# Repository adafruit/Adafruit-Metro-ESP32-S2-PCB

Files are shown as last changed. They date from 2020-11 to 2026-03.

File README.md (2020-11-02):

## Adafruit Metro ESP32-S2 PCB

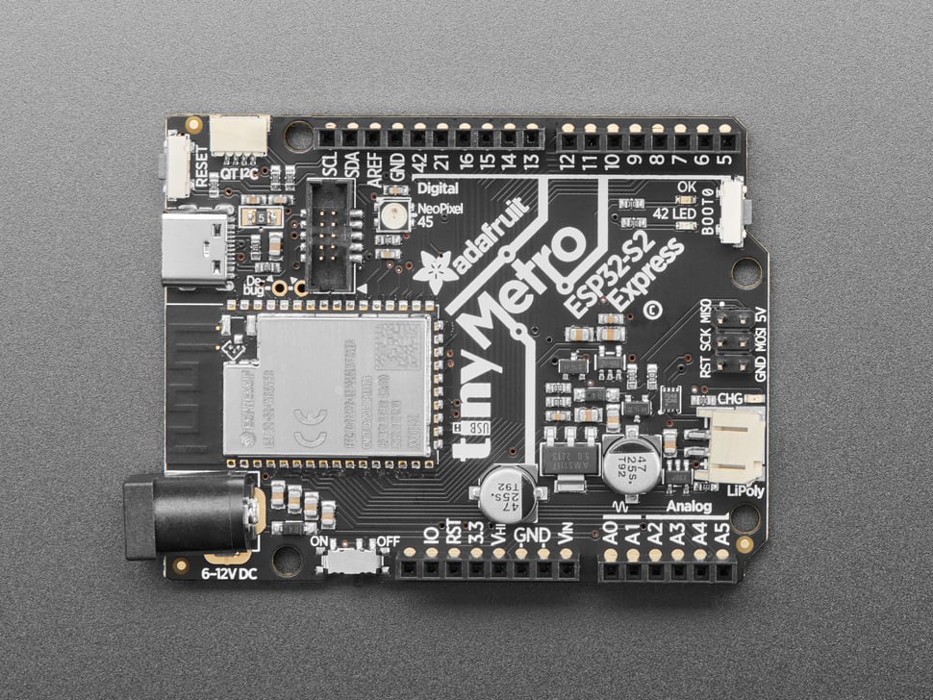
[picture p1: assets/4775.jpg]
<a href="http://www.adafruit.com/products/4775"><br/>
Click here to purchase one from the Adafruit shop</a>

PCB files for the Adafruit Metro ESP32-S2.

Format is EagleCAD schematic and board layout
* https://www.adafruit.com/product/4775

### Description

What's Metro shaped and has an ESP32-S2 WiFi module? What has a STEMMA QT connector for I2C devices, and a Lipoly charger circuit? What's finishing up testing and nearly ready for fabrication? That's right - its the new Adafruit Metro ESP32-S2! With native USB and a load of PSRAM this board is perfect for use with CircuitPython or Arduino, to add low-cost WiFi while keeping shield-compatibility

Features:

* ESP32-S2 240MHz Tensilica processor - the next generation of ESP32, now with native USB so it can act like a keyboard/mouse, MIDI device, disk drive, etc!
* WROVER module has FCC/CE certification and comes with 4 MByte of Flash and 8 MByte of PSRAM - you can have huge data buffers
* Lotsa power options - 6-12VDC barrel jack or USB type C or Lipoly battery
* Built-in battery charging when powered over DC or USB
* UNO-shape so shields can plug in
* Reset and DFU (BOOT0) buttons to get into the ROM bootloader (which is a USB serial port so you don't need a separate cable!)
* Serial debug pins (optional, for checking the hardware serial debug console)
* JTAG pads for advanced debugging access.
* On/Off switch
* STEMMA QT connector for I2C devices
* On/Charge/User LEDs + status NeoPixel
* Works with Arduino or CircuitPython
* 53.2mm x 72mm / 2" x 2.8"
* Height (w/ barrel jack): 14.8mm / 0.6"
* Weight: 22.5g

### License

Adafruit invests time and resources providing this open source design, please support Adafruit and open-source hardware by purchasing products from [Adafruit](https://www.adafruit.com)!

Designed by Limor Fried/Ladyada for Adafruit Industries.

Creative Commons Attribution/Share-Alike, all text above must be included in any redistribution.
See license.txt for additional details.

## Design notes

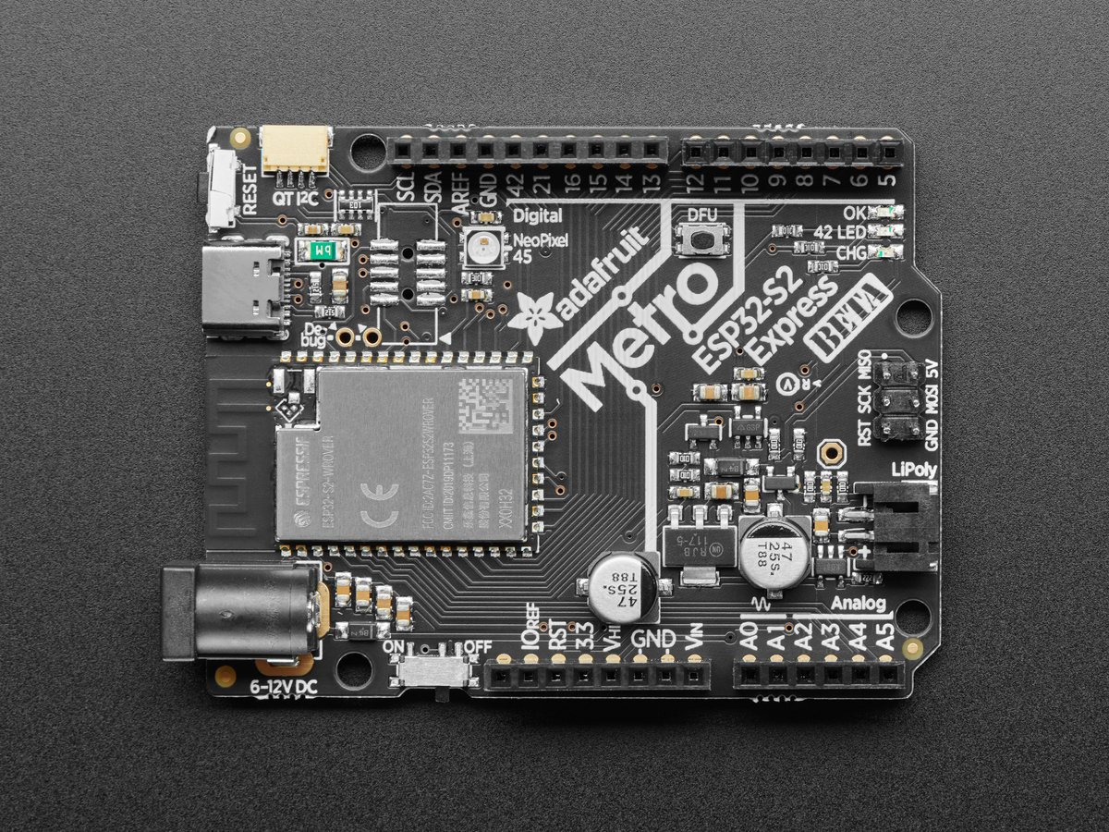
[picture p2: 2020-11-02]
assets/4775_revA.jpg

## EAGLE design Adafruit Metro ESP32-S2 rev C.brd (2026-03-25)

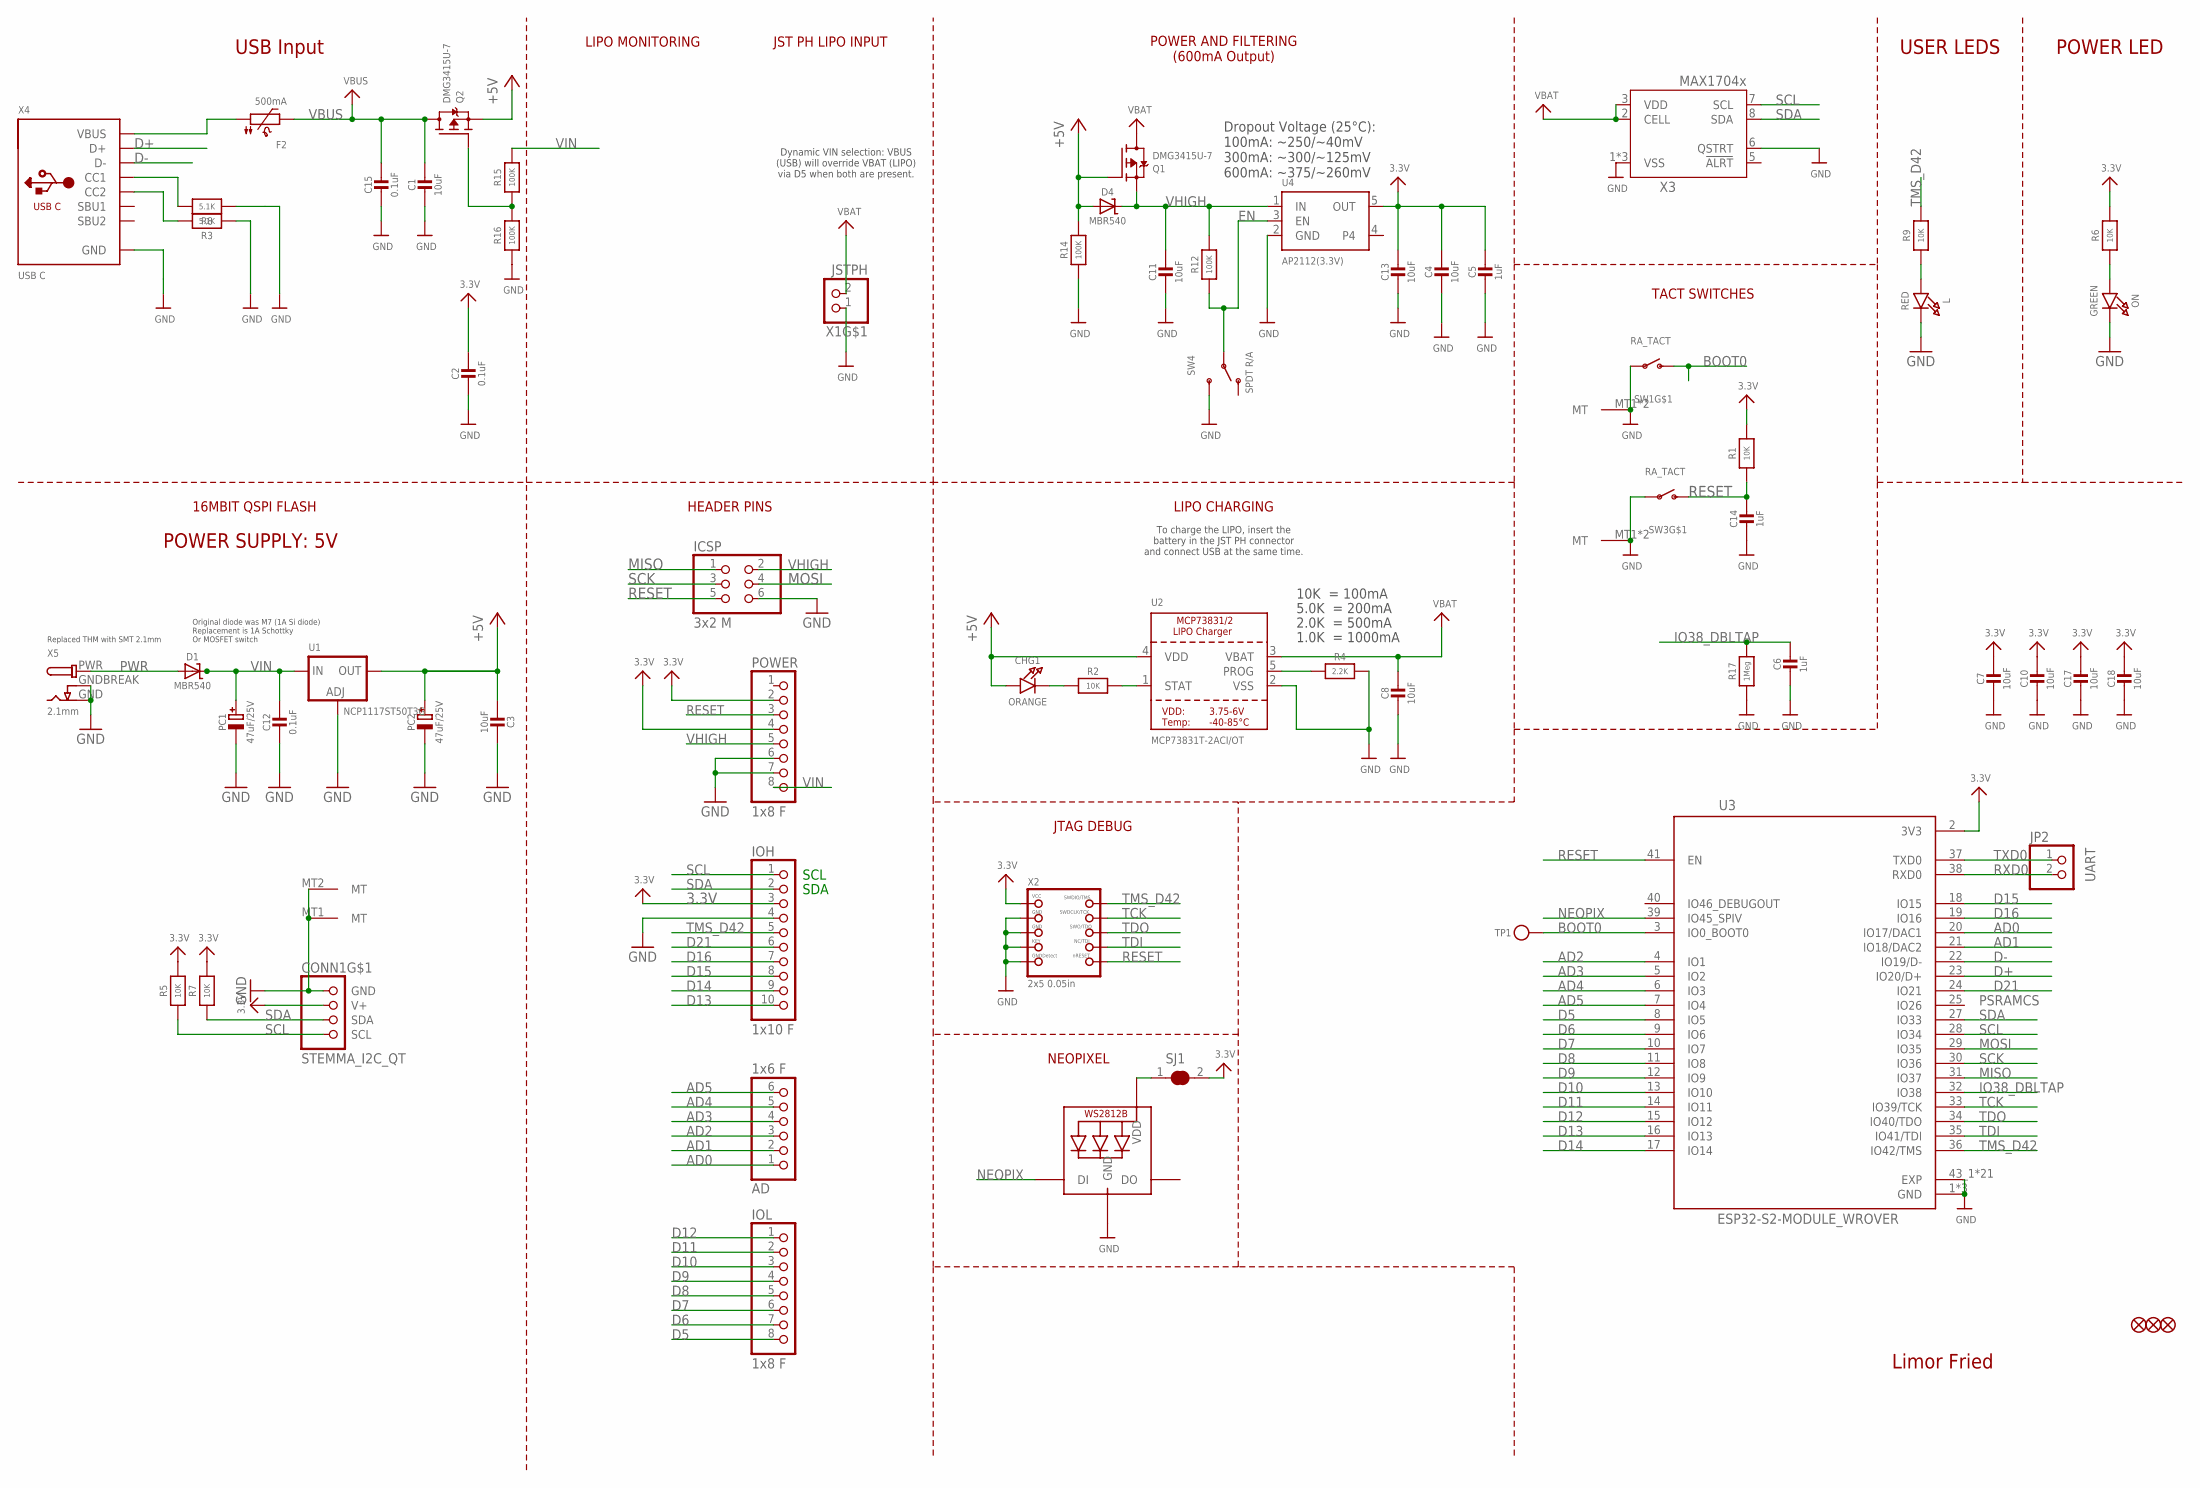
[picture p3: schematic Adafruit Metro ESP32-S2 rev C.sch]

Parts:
AD: 1x6 F; 1X06_OVALWAVE
C1, C3, C4, C7, C8, C10, C11, C13, C17, C18: 10uF; 0805-NO
C2, C12, C15: 0.1uF; 0603-NO
C5, C6, C14: 1uF; 0603-NO
CHG1: ORANGE; CHIPLED_0603_NOOUTLINE
CONN1: STEMMA_I2C_QT; JST_SH4
D1, D4: MBR540; SOD-123
F2: 500mA; 1206
FD1, FD2, FD3: FIDUCIAL_1MM
ICSP: 3x2 M; 2X03_ROUND_70MIL
IOH: 1x10 F; 1X10_OVALWAVE
IOL: 1x8 F; 1X08_OVALWAVE
JP2: UART; 1X02_ROUND
L: RED; CHIPLED_0603_NOOUTLINE
LED1: WS2812B_3535FULL; LED3535_FULLPADS
ON: GREEN; CHIPLED_0603_NOOUTLINE
PC1, PC2: 47uF/25V; PANASONIC_D
POWER: 1x8 F; 1X08_OVALWAVE
Q1, Q2: DMG3415U-7; SOT23-R
R1, R2, R5, R6, R7, R9: 10K; 0603-NO
R3, R8: 5.1K; 0603-NO
R4: 2.2K; 0603-NO
R12, R14, R15, R16: 100K; 0603-NO
R17: 1Meg; 0603-NO
SJ1: SOLDERJUMPER_CLOSED; SOLDERJUMPER_CLOSEDWIRE
SW1, SW3: RA_TACT; SPST_TACTILE_RA
SW4: SPDT R/A; SPDT_SMT_SSSS811101
TP1: TESTPOINTROUND1.5MMNO; TESTPOINT_ROUND_1.5MM_NO
U1: NCP1117ST50T3G; SOT223-R
U2: MCP73831T-2ACI/OT; SOT23-5
U3: ESP32-S2-MODULE_WROVER; MODULE_ESP32-S2-WROVER
U4: AP2112(3.3V); SOT23-5; JLC_ROTATION 0
X1: JSTPH; JSTPH2_BATT
X2: 2x5 0.05in; 2X05_1.27MM_BOX_POSTS
X3: MAX17048/T; TDFN8_2X2MM
X4: USB C; USB_C_CUSB31-CFM2AX-01-X
X5: 2.1mm; DCJACK_2MM_PTH

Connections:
3.3V: C2.1, C4.1, C5.1, C7.1, C10.1, C13.1, C17.1, C18.1, CONN1.2 (V+), IOH.3, POWER.2, POWER.4, R1.2, R5.2, R6.2, R7.2, SJ1.2, U3.2 (3V3), U4.5 (OUT), X2.1 (VCC)
+5V: C3.2, CHG1.A, D4.A, PC2.+, Q1.1 (G), Q2.2 (S), R14.2, U1.2 (OUT), U1.4 (OUT), U2.4 (VDD)
AD0: AD.1, U3.20 (IO17/DAC1)
AD1: AD.2, U3.21 (IO18/DAC2)
AD2: AD.3, U3.4 (IO1)
AD3: AD.4, U3.5 (IO2)
AD4: AD.5, U3.6 (IO3)
AD5: AD.6, U3.7 (IO4)
BOOT0: SW1.2 (S), TP1.P$1, U3.3 (IO0_BOOT0)
D5: IOL.8, U3.8 (IO5)
D6: IOL.7, U3.9 (IO6)
D7: IOL.6, U3.10 (IO7)
D8: IOL.5, U3.11 (IO8)
D9: IOL.4, U3.12 (IO9)
D10: IOL.3, U3.13 (IO10)
D11: IOL.2, U3.14 (IO11)
D12: IOL.1, U3.15 (IO12)
D13: IOH.10, U3.16 (IO13)
D14: IOH.9, U3.17 (IO14)
D15: IOH.8, U3.18 (IO15)
D16: IOH.7, U3.19 (IO16)
D21: IOH.6, U3.24 (IO21)
D+: U3.23 (IO20/D+), X4.A6 (D+), X4.B6 (D+)
D-: U3.22 (IO19/D-), X4.A7 (D-), X4.B7 (D-)
EN: R12.1, SW4.B, U4.3 (EN)
GND: C1.2, C2.2, C3.1, C4.2, C5.2, C6.2, C7.2, C8.2, C10.2, C11.2, C12.2, C13.2, C14.2, C15.2, C17.2, C18.2, CONN1.1 (GND), CONN1.MT1 (MT), CONN1.MT2 (MT), ICSP.6, IOH.4, L.C, LED1.4 (GND), ON.C, PC1.-, PC2.-, POWER.6, POWER.7, R3.1, R4.2, R8.1, R14.1, R16.1, R17.1, SW1.1, SW1.MT1 (MT), SW1.MT2 (MT), SW3.1, SW3.MT1 (MT), SW3.MT2 (MT), SW4.C (S), U1.1 (ADJ), U2.2 (VSS), U3.1 (GND), U3.26 (GND), U3.42 (GND), U3.43_1 (EXP), U3.43_2 (EXP), U3.43_3 (EXP), U3.43_4 (EXP), U3.43_5 (EXP), U3.43_6 (EXP), U3.43_7 (EXP), U3.43_8 (EXP), U3.43_9 (EXP), U3.43_10 (EXP), U3.43_11 (EXP), U3.43_12 (EXP), U3.43_13 (EXP), U3.43_14 (EXP), U3.43_15 (EXP), U3.43_16 (EXP), U3.43_17 (EXP), U3.43_18 (EXP), U3.43_19 (EXP), U3.43_20 (EXP), U3.43_21 (EXP), U4.2 (GND), X1.1, X2.3 (GND), X2.5 (GND), X2.7 (KEY), X2.9 (GNDDETECT), X3.1 (VSS), X3.4 (VSS), X3.6 (QSTRT), X3.THERMAL (VSS), X4.A1B12 (GND), X4.B1A12 (GND), X5.GND, X5.GNDBREAK
IO38_DBLTAP: C6.1, R17.2, U3.32 (IO38)
MISO: ICSP.1, U3.31 (IO37)
MOSI: ICSP.4, U3.29 (IO35)
unnamed: L.A, R9.1
unnamed: Q2.1 (G), R15.1, R16.2
unnamed: ON.A, R6.1
unnamed: CHG1.C, R2.1
unnamed: LED1.2 (VDD), SJ1.1
unnamed: R2.2, U2.1 (STAT)
unnamed: R8.2, X4.A5 (CC1)
unnamed: R3.2, X4.B5 (CC2)
unnamed: R4.1, U2.5 (PROG)
unnamed: F2.1, X4.A4B9 (VBUS), X4.B4A9 (VBUS)
NEOPIX: LED1.1 (DI), U3.39 (IO45_SPIV)
PWR: D1.A, X5.PWR
RESET: C14.1, ICSP.5, POWER.3, R1.1, SW3.2 (S), U3.41 (EN), X2.10 (NRESET)
RXD0: JP2.2, U3.38 (RXD0)
SCK: ICSP.3, U3.30 (IO36)
SCL: CONN1.4 (SCL), IOH.1, R5.1, U3.28 (IO34), X3.7 (SCL)
SDA: CONN1.3 (SDA), IOH.2, R7.1, U3.27 (IO33), X3.8 (SDA)
TCK: U3.33 (IO39/TCK), X2.4 (SWDCLK)
TDI: U3.35 (IO41/TDI), X2.8 (TDI)
TDO: U3.34 (IO40/TDO), X2.6 (SWO)
TMS_D42: IOH.5, R9.2, U3.36 (IO42/TMS), X2.2 (SWDIO)
TXD0: JP2.1, U3.37 (TXD0)
VBAT: C8.1, Q1.3 (D), U2.3 (VBAT), X1.2, X3.2 (CELL), X3.3 (VDD)
VBUS: C1.1, C15.1, F2.2, Q2.3 (D)
VHIGH: C11.1, D4.C, ICSP.2, POWER.5, Q1.2 (S), R12.2, U4.1 (IN)
VIN: C12.1, D1.C, PC1.+, POWER.8, R15.2, U1.3 (IN)

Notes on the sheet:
SDA
SCL
Limor Fried
USB Input
POWER LED
USER LEDS
10K = 100mA
5.0K = 200mA
2.0K = 500mA
1.0K = 1000mA
LIPO CHARGING
LIPO MONITORING
To charge the LIPO, insert the battery in the JST PH connector and connect USB at the same time.
POWER AND FILTERING (600mA Output)
JST PH LIPO INPUT
Dynamic VIN selection: VBUS (USB) will override VBAT (LIPO) via D5 when both are present.
Dropout Voltage (25°C): 100mA: ~250/~40mV 300mA: ~300/~125mV 600mA: ~375/~260mV
HEADER PINS
16MBIT QSPI FLASH
TACT SWITCHES
JTAG DEBUG
NEOPIXEL
Original diode was M7 (1A Si diode) Replacement is 1A Schottky Or MOSFET switch
Replaced THM with SMT 2.1mm
POWER SUPPLY: 5V
PSRAMCS

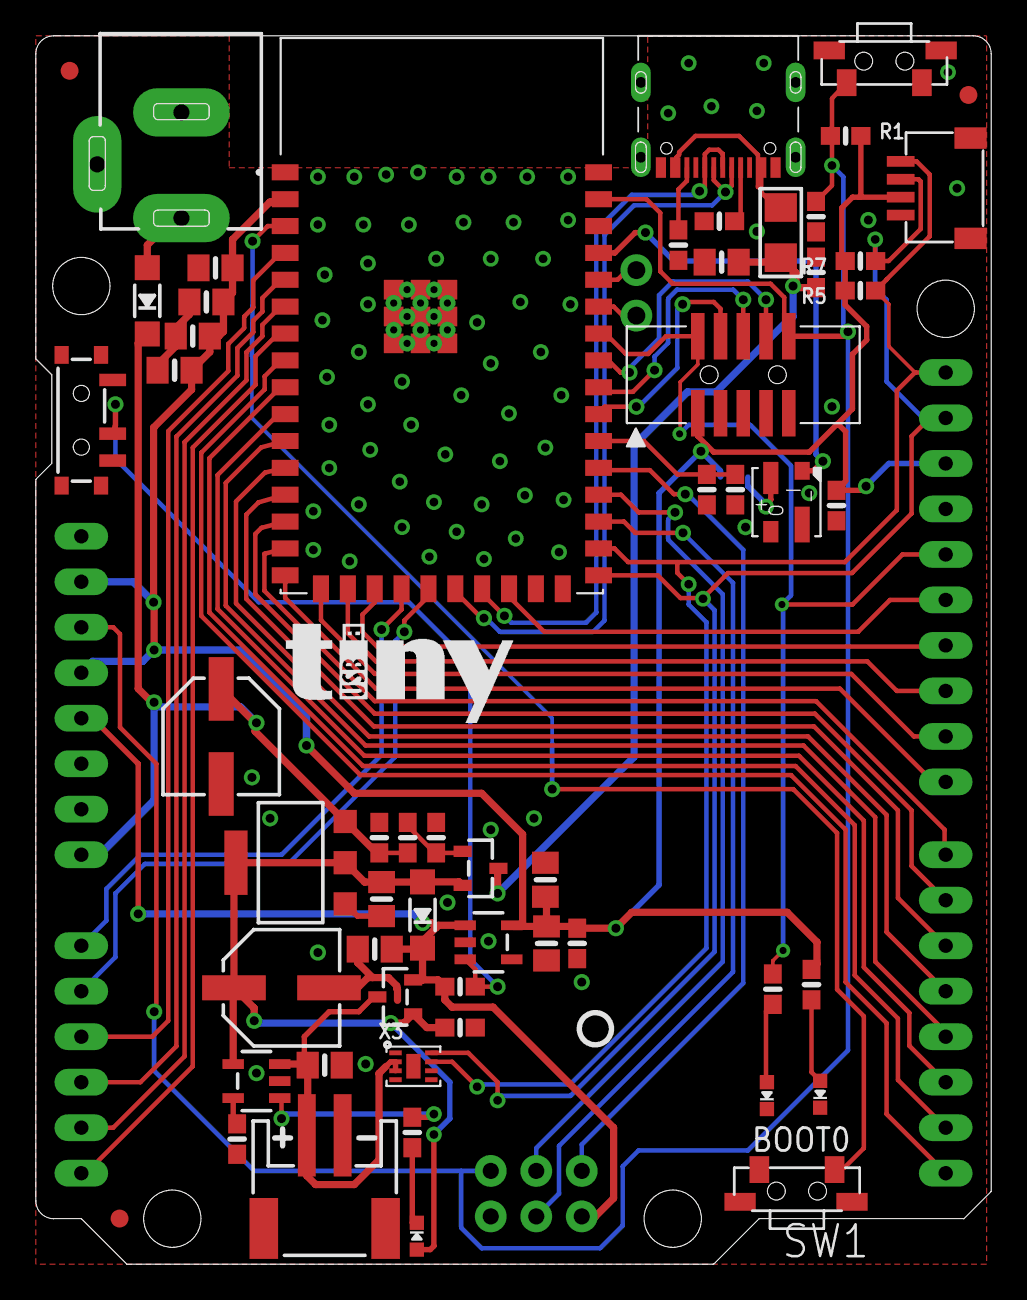
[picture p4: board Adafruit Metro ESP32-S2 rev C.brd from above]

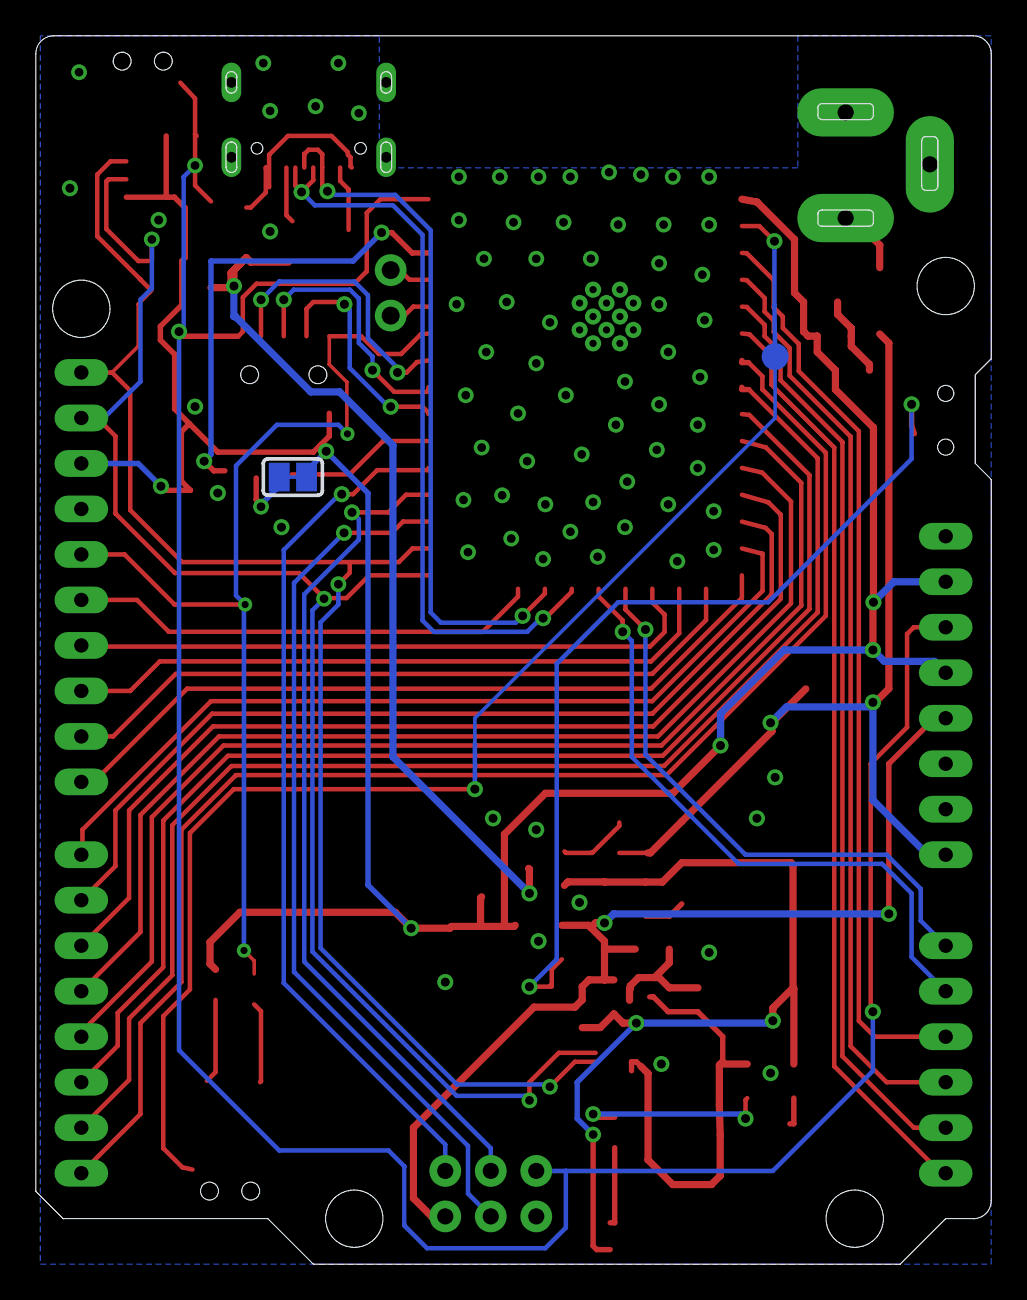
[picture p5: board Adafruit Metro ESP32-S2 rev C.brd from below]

Board: 2 copper layers, 53.3 x 68.6 mm, 69 parts (3 on the bottom side), 55 nets.

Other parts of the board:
U$14: TINYUSB_0.5IN
U$15: PCBFEAT-REV-040
U$52: ESP32S2_TOP
U$53: ESP32S2_BOT

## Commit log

2020-11-02 Adding board files.
    [Adafruit Metro ESP32-S2.brd, Adafruit Metro ESP32-S2.sch]
2026-03-25 add rev c
    [Adafruit Metro ESP32-S2 rev C.brd, Adafruit Metro ESP32-S2 rev C.sch]

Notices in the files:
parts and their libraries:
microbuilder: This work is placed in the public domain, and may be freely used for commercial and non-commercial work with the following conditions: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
